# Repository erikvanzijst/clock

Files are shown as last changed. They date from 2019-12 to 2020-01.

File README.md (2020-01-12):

# 24H Digital Clock

This project contains the schematics and PCB layout for a 24-hour digital
quartz clock with self-dimming LED display.

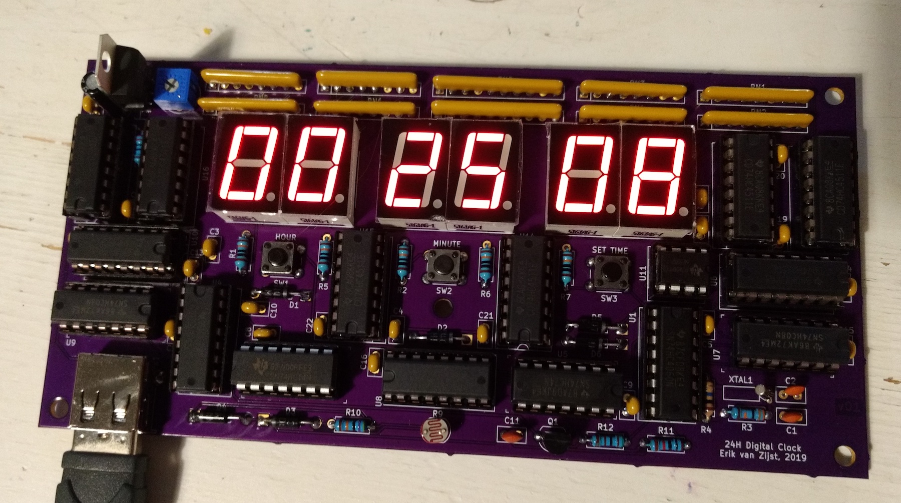
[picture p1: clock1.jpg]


Full write-up is at https://medium.com/@erikvanzijst/a-digital-quartz-clock-from-scratch-a80ec5e427

## Kicad symbol and footprint libraries
The project uses the [DigiKey Kicad symbol and footprint libraries](https://github.com/Digi-Key/digikey-kicad-library).
After cloning or downloading those locally, [add them to the Kicad Symbol and
Footprint libraries](https://forum.digikey.com/t/importing-the-digi-key-kicad-library-into-kicad-5-0-0/4075).

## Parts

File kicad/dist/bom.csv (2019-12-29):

Reference | Quantity | Value | MPN | Digikey Part Number | Price | Total Price | Part Page | Footprint | Category | DK_Datasheet_Link | DK_Detail_Page | Description | Digi-Key_PN | Family | MPN | Manufacturer | Status
C11 | 1 | 47nF |  |  |  |  |  | Capacitor_THT:C_Disc_D5.0mm_W2.5mm_P2.50mm
C12 | 1 | 10nF |  |  |  |  |  | Capacitor_THT:C_Disc_D5.0mm_W2.5mm_P2.50mm
C2 C1 | 2 | 22pF |  |  |  |  |  | Capacitor_THT:C_Disc_D5.0mm_W2.5mm_P2.50mm
C4 C3 C5 C14 C15 C21 C16 C22 C8 C10 C18 C23 C13 C17 C9 C19 C20 C24 | 18 | 100nF | C320C104J5R5TA | 399-9775-ND | $0.48 |  | https://www.digikey.com/product-detail/en/kemet/C320C104J5R5TA/399-9775-ND/3726074 | Capacitor_THT:C_Disc_D5.0mm_W2.5mm_P2.50mm
C6 | 1 | 10uF |  |  |  |  |  | Capacitor_THT:C_Disc_D5.0mm_W2.5mm_P2.50mm
C7 | 1 | 10uF |  |  |  |  |  | Capacitor_THT:C_Radial_D5.0mm_H11.0mm_P2.00mm
D1 D2 D3 D4 | 4 | D |  |  |  |  |  | digikey-footprints:Diode_DO-35_P10mm
J1 | 1 | USB-SS-52100-001 | SS-52100-001 | 380-1412-ND | $0.44 |  | https://www.digikey.com/products/en?keywords=380-1412-ND | KiCad:USB_A_Stewart_SS-52100-001_Horizontal | Connectors, Interconnects |  | https://www.digikey.com/product-detail/en/stewart-connector/SS-52100-001/380-1412-ND/7902377 | CONN RCPT USB2.0 TYPEA 4POS R/A | 380-1412-ND | USB, DVI, HDMI Connectors | SS-52100-001 | Stewart Connector | Active
Q1 | 1 | PN2222A |  |  |  |  |  | Package_TO_SOT_THT:TO-92_Inline_Wide
R10 | 1 | 10K |  |  |  |  |  | Resistor_THT:R_Axial_DIN0207_L6.3mm_D2.5mm_P7.62mm_Horizontal
R11 | 1 | 5.1K |  |  |  |  |  | Resistor_THT:R_Axial_DIN0207_L6.3mm_D2.5mm_P7.62mm_Horizontal
R3 | 1 | 330k | SFR2500003303JA500 | BC4849CT-ND | $0.13 |  | https://www.digikey.com/product-detail/en/vishay-bc-components/SFR2500003303JA500/BC4849CT-ND/7352279 | Resistor_THT:R_Axial_DIN0207_L6.3mm_D2.5mm_P7.62mm_Horizontal
R4 | 1 | 10M | CF14JT10M0 | CF14JT10M0CT-ND | $0.10 |  | https://www.digikey.com/product-detail/en/stackpole-electronics-inc/CF14JT10M0/CF14JT10M0CT-ND/1830444 | Resistor_THT:R_Axial_DIN0207_L6.3mm_D2.5mm_P7.62mm_Horizontal
R6 R2 R5 R1 | 4 | 100K | SFR2500001003FR500 | PPC100KYCT-ND | $0.13 |  | https://www.digikey.com/products/en/resistors/through-hole-resistors/53?k=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 | Resistor_THT:R_Axial_DIN0207_L6.3mm_D2.5mm_P7.62mm_Horizontal
R7 | 1 | 220R | SFR2500002200FR500 | PPC220YCT-ND | $0.13 |  | https://www.digikey.com/product-detail/en/vishay-bc-components/SFR2500002200FR500/PPC220YCT-ND/596957 | Resistor_THT:R_Axial_DIN0207_L6.3mm_D2.5mm_P7.62mm_Horizontal
R8 | 1 | VT93xx | PDV-P7002 | PDV-P7002-ND | $1.41 |  | https://www.digikey.com/product-detail/en/advanced-photonix/PDV-P7002/PDV-P7002-ND/481921 | OptoDevice:R_LDR_4.9x4.2mm_P2.54mm_Vertical
R9 | 1 | 1M |  |  |  |  |  | Resistor_THT:R_Axial_DIN0207_L6.3mm_D2.5mm_P7.62mm_Horizontal
RN1 RN2 RN3 RN4 RN5 RN6 RN7 RN8 | 8 | 150R | 4608X-102-151LF | 4608X-2-151LF-ND | $0.57 |  | https://www.digikey.com/product-detail/en/4608X-102-151LF/4608X-2-151LF-ND/1089113/?itemSeq=299231447 | Resistor_THT:R_Array_SIP8
RN9 RN10 | 2 | 150R | 4610X-102-151LF | 4610X-2-151LF-ND | $0.58 |  | https://www.digikey.com/product-detail/en/4610X-102-151LF/4610X-2-151LF-ND/1089226/?itemSeq=299231416 | Resistor_THT:R_Array_SIP10
RV1 | 1 | 500R | 3362P-1-501LF | 3362P-501LF-ND | $1.02 |  | https://www.digikey.com/product-detail/en/3362P-1-501LF/3362P-501LF-ND/1088420/?itemSeq=298643928 | Potentiometer_THT:Potentiometer_Bourns_3339P_Vertical_HandSoldering
SW1 | 1 | HOUR |  |  |  |  |  | Button_Switch_THT:SW_PUSH_6mm_H4.3mm
SW2 | 1 | MIN |  |  |  |  |  | Button_Switch_THT:SW_PUSH_6mm_H4.3mm
SW3 | 1 | TIME |  |  |  |  |  | Button_Switch_THT:SW_PUSH_6mm_H4.3mm
U1 | 1 | 74HC4060 | SN74HC4060N | 296-8209-5-ND | $0.58 |  | https://www.digikey.com/product-detail/en/texas-instruments/SN74HC4060N/296-8209-5-ND/386620 | Package_DIP:DIP-16_W7.62mm_Socket
U11 | 1 | NE555P | NE555P | 296-1411-5-ND | $0.45 |  | https://www.digikey.com/product-detail/en/NE555P/296-1411-5-ND/277057/?itemSeq=291832413 | Package_DIP:DIP-8_W7.62mm_Socket | Integrated Circuits (ICs) | http://www.ti.com/general/docs/suppproductinfo.tsp?distId=10 | /product-detail/en/texas-instruments/NE555P/296-1411-5-ND/277057 | IC OSC SINGLE TIMER 100KHZ 8-DIP | 296-1411-5-ND | Clock/Timing - Programmable Timers and Oscillators | NE555P | Texas Instruments | Active
U12 U14 U15 U16 U13 U17 | 6 | 74HC4511 | CD74HC4511E | 296-14537-5-ND | $0.85 |  | https://www.digikey.com/product-detail/en/texas-instruments/CD74HC4511E/296-14537-5-ND/555825 | Package_DIP:DIP-16_W7.62mm_Socket
U18 U19 U20 U21 U23 U22 | 6 | KCSC02-105 |  |  |  |  | https://www.velleman.eu/downloads/29/infosheets/vmp502_sma42056etc.pdf | Display_7Segment:7SegmentLED_LTS6760_LTS6780
U2 | 1 | LD1117V | LD1117V | 497-7310-5-ND | $0.55 |  | https://www.digikey.com/product-detail/en/LD1117V/497-7310-5-ND/1038361/?itemSeq=298871373 | digikey-footprints:TO-220-3 | Integrated Circuits (ICs) | http://www.st.com/content/ccc/resource/technical/document/datasheet/99/3b/7d/91/91/51/4b/be/CD00000544.pdf/files/CD00000544.pdf/jcr:content/translations/en.CD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 | /product-detail/en/stmicroelectronics/LD1117V33/497-1491-5-ND/586012 | IC REG LINEAR 1.8V-5V 800MA TO220AB | 497-7310-5-ND | PMIC - Voltage Regulators - Linear | LD1117V | STMicroelectronics | Active
U3 | 1 | 74HC14 | SN74HC14N | 296-1577-5-ND | $0.55 |  | https://www.digikey.com/product-detail/en/texas-instruments/SN74HC14N/296-1577-5-ND/277223 | clock:Socket_DIP-14_0.775in_Conn
U4 | 1 | 74HC157 | SN74HC157N | 296-1578-5-ND | $0.50 |  | https://www.digikey.com/product-detail/en/SN74HC157N/296-1578-5-ND/277224/?itemSeq=291832408 | Package_DIP:DIP-16_W7.62mm_Socket
U5 | 1 | SN74HC74N | SN74HC74N | 296-1602-5-ND | $0.48 |  | https://www.digikey.com/product-detail/en/texas-instruments/SN74HC74N/296-1602-5-ND/277248 | clock:Socket_DIP-14_0.775in_Conn | Integrated Circuits (ICs) | http://www.ti.com/general/docs/suppproductinfo.tsp?distId=10 | /product-detail/en/texas-instruments/SN74HC74N/296-1602-5-ND/277248 | IC FF D-TYPE DUAL 1BIT 14DIP | 296-1602-5-ND | Logic - Flip Flops | SN74HC74N | Texas Instruments | Active
U6 U8 U10 | 3 | 74HC390 | CD74HC390E | 296-9199-5-ND | $0.70 |  | https://www.digikey.com/product-detail/en/texas-instruments/CD74HC390E/296-9199-5-ND/376757 | Package_DIP:DIP-16_W7.62mm_Socket
U9 U7 | 2 | 74HC08 |  |  |  |  |  | clock:Socket_DIP-14_0.775in_Conn
XTAL1 | 1 | ECS-_327-12_5-34B-TR | ECS-.327-CDX-1038 | XC2121-ND | $0.60 |  | https://www.digikey.com/product-detail/en/ecs-inc/ECS-.327-CDX-1038/XC2121-ND/5875500 | Crystal:Crystal_DS26_D2.0mm_L6.0mm_Horizontal | Crystals, Oscillators, Resonators | http://www.ecsxtal.com/store/pdf/ecx-31b.pdf | /product-detail/en/ecs-inc/ECS-.327-12.5-34B-TR/XC1617CT-ND/1693786 | CRYSTAL 32.7680KHZ 12.5PF SMD | XC1617CT-ND | Crystals | ECS-.327-12.5-34B-TR | ECS Inc. | Active
DIP Socket 8 Pins | 1 | DIP Socket 8 Pins | ED08DT | ED3044-5-ND | $0.16 |  | https://www.digikey.com/product-detail/en/on-shore-technology-inc/ED08DT/ED3044-5-ND/4147594
DIP Socket 14 Pins | 4 | DIP Socket 14 Pins | A 14-LC-TT | AE9989-ND | $0.22 |  | https://www.digikey.com/product-detail/en/assmann-wsw-components/A-14-LC-TT/AE9989-ND/821743
DIP Socket 16 Pins | 11 | DIP Socket 16 Pins | ED16DT | ED3046-5-ND | $0.19 |  | https://www.digikey.com/product-detail/en/on-shore-technology-inc/ED16DT/ED3046-5-ND/4147596

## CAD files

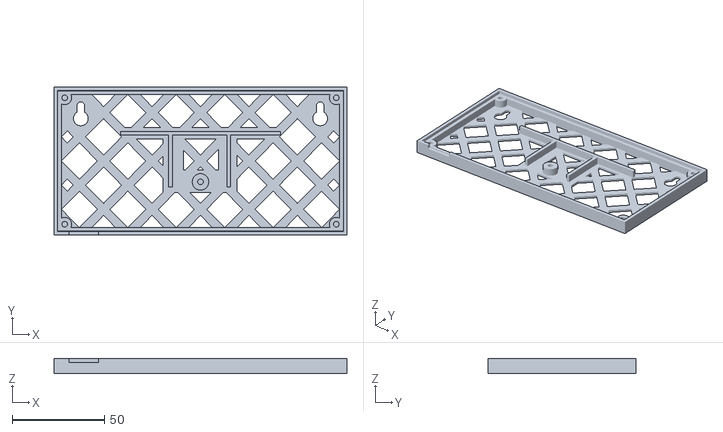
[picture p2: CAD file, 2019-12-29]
base_plate.stl
158.5 x 80.0 x 8.00

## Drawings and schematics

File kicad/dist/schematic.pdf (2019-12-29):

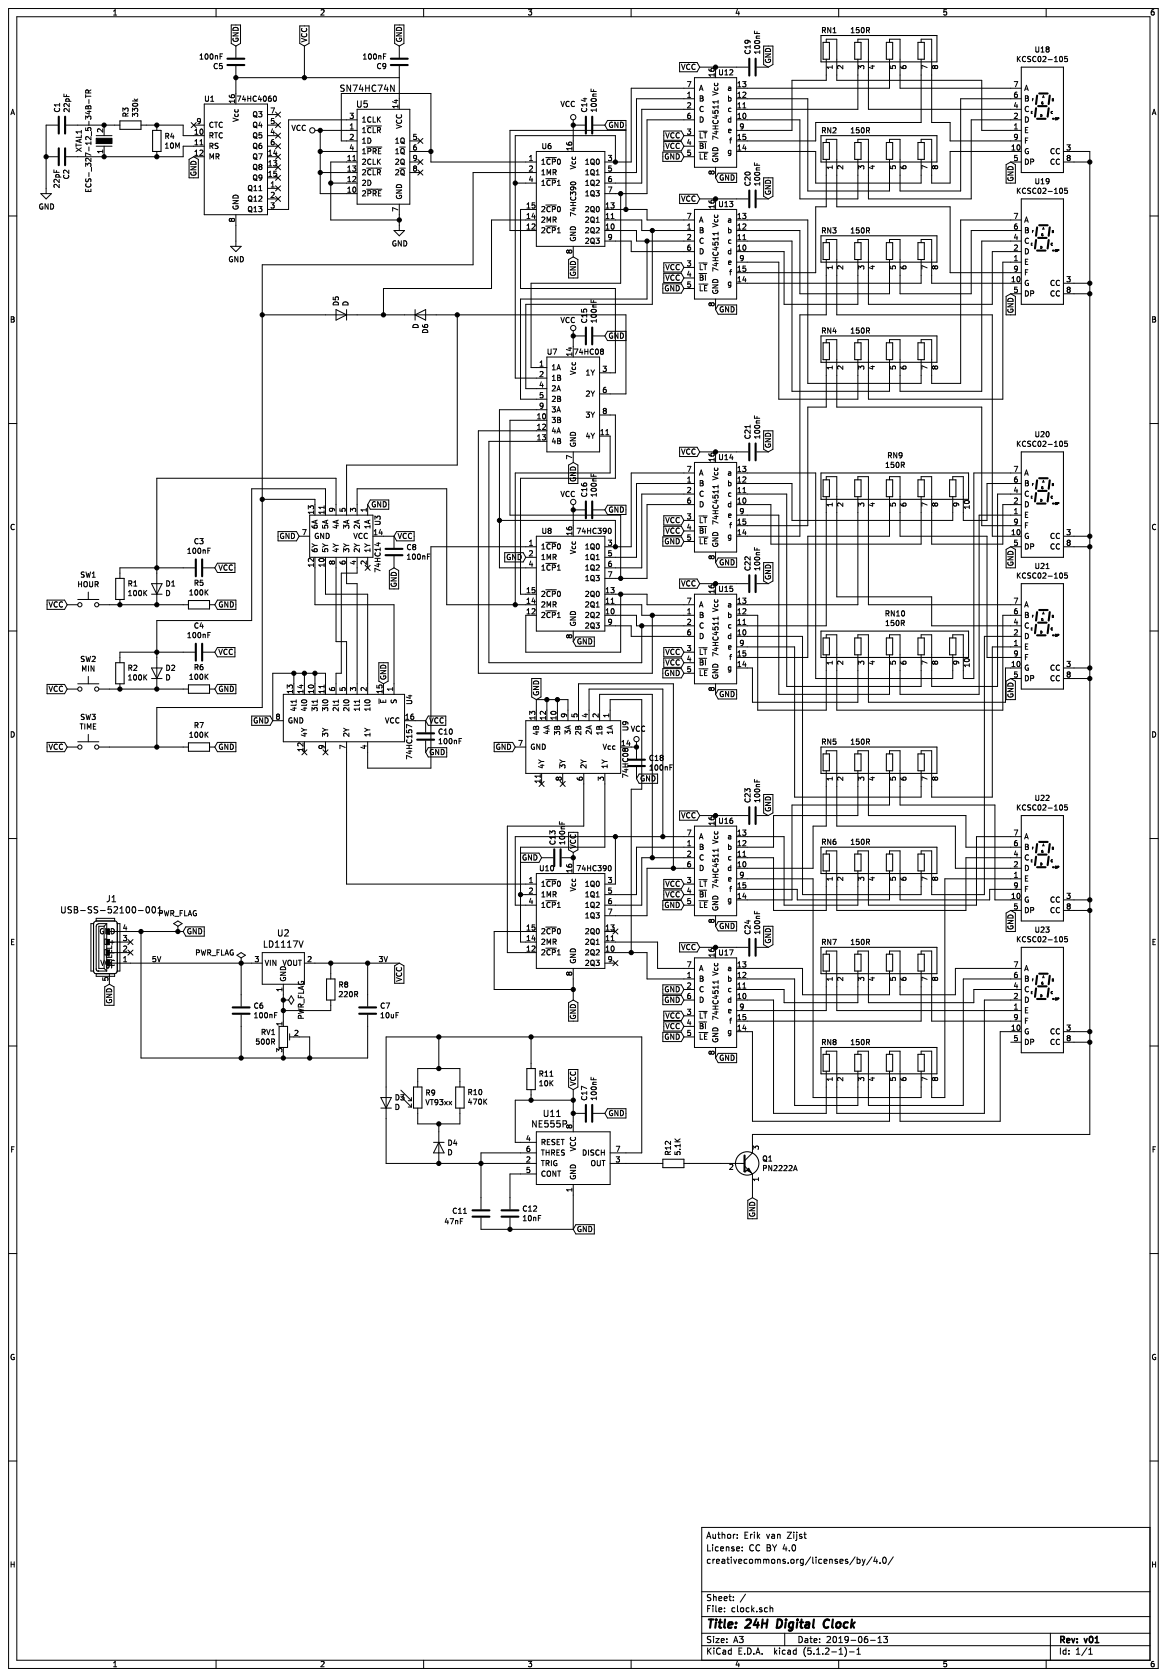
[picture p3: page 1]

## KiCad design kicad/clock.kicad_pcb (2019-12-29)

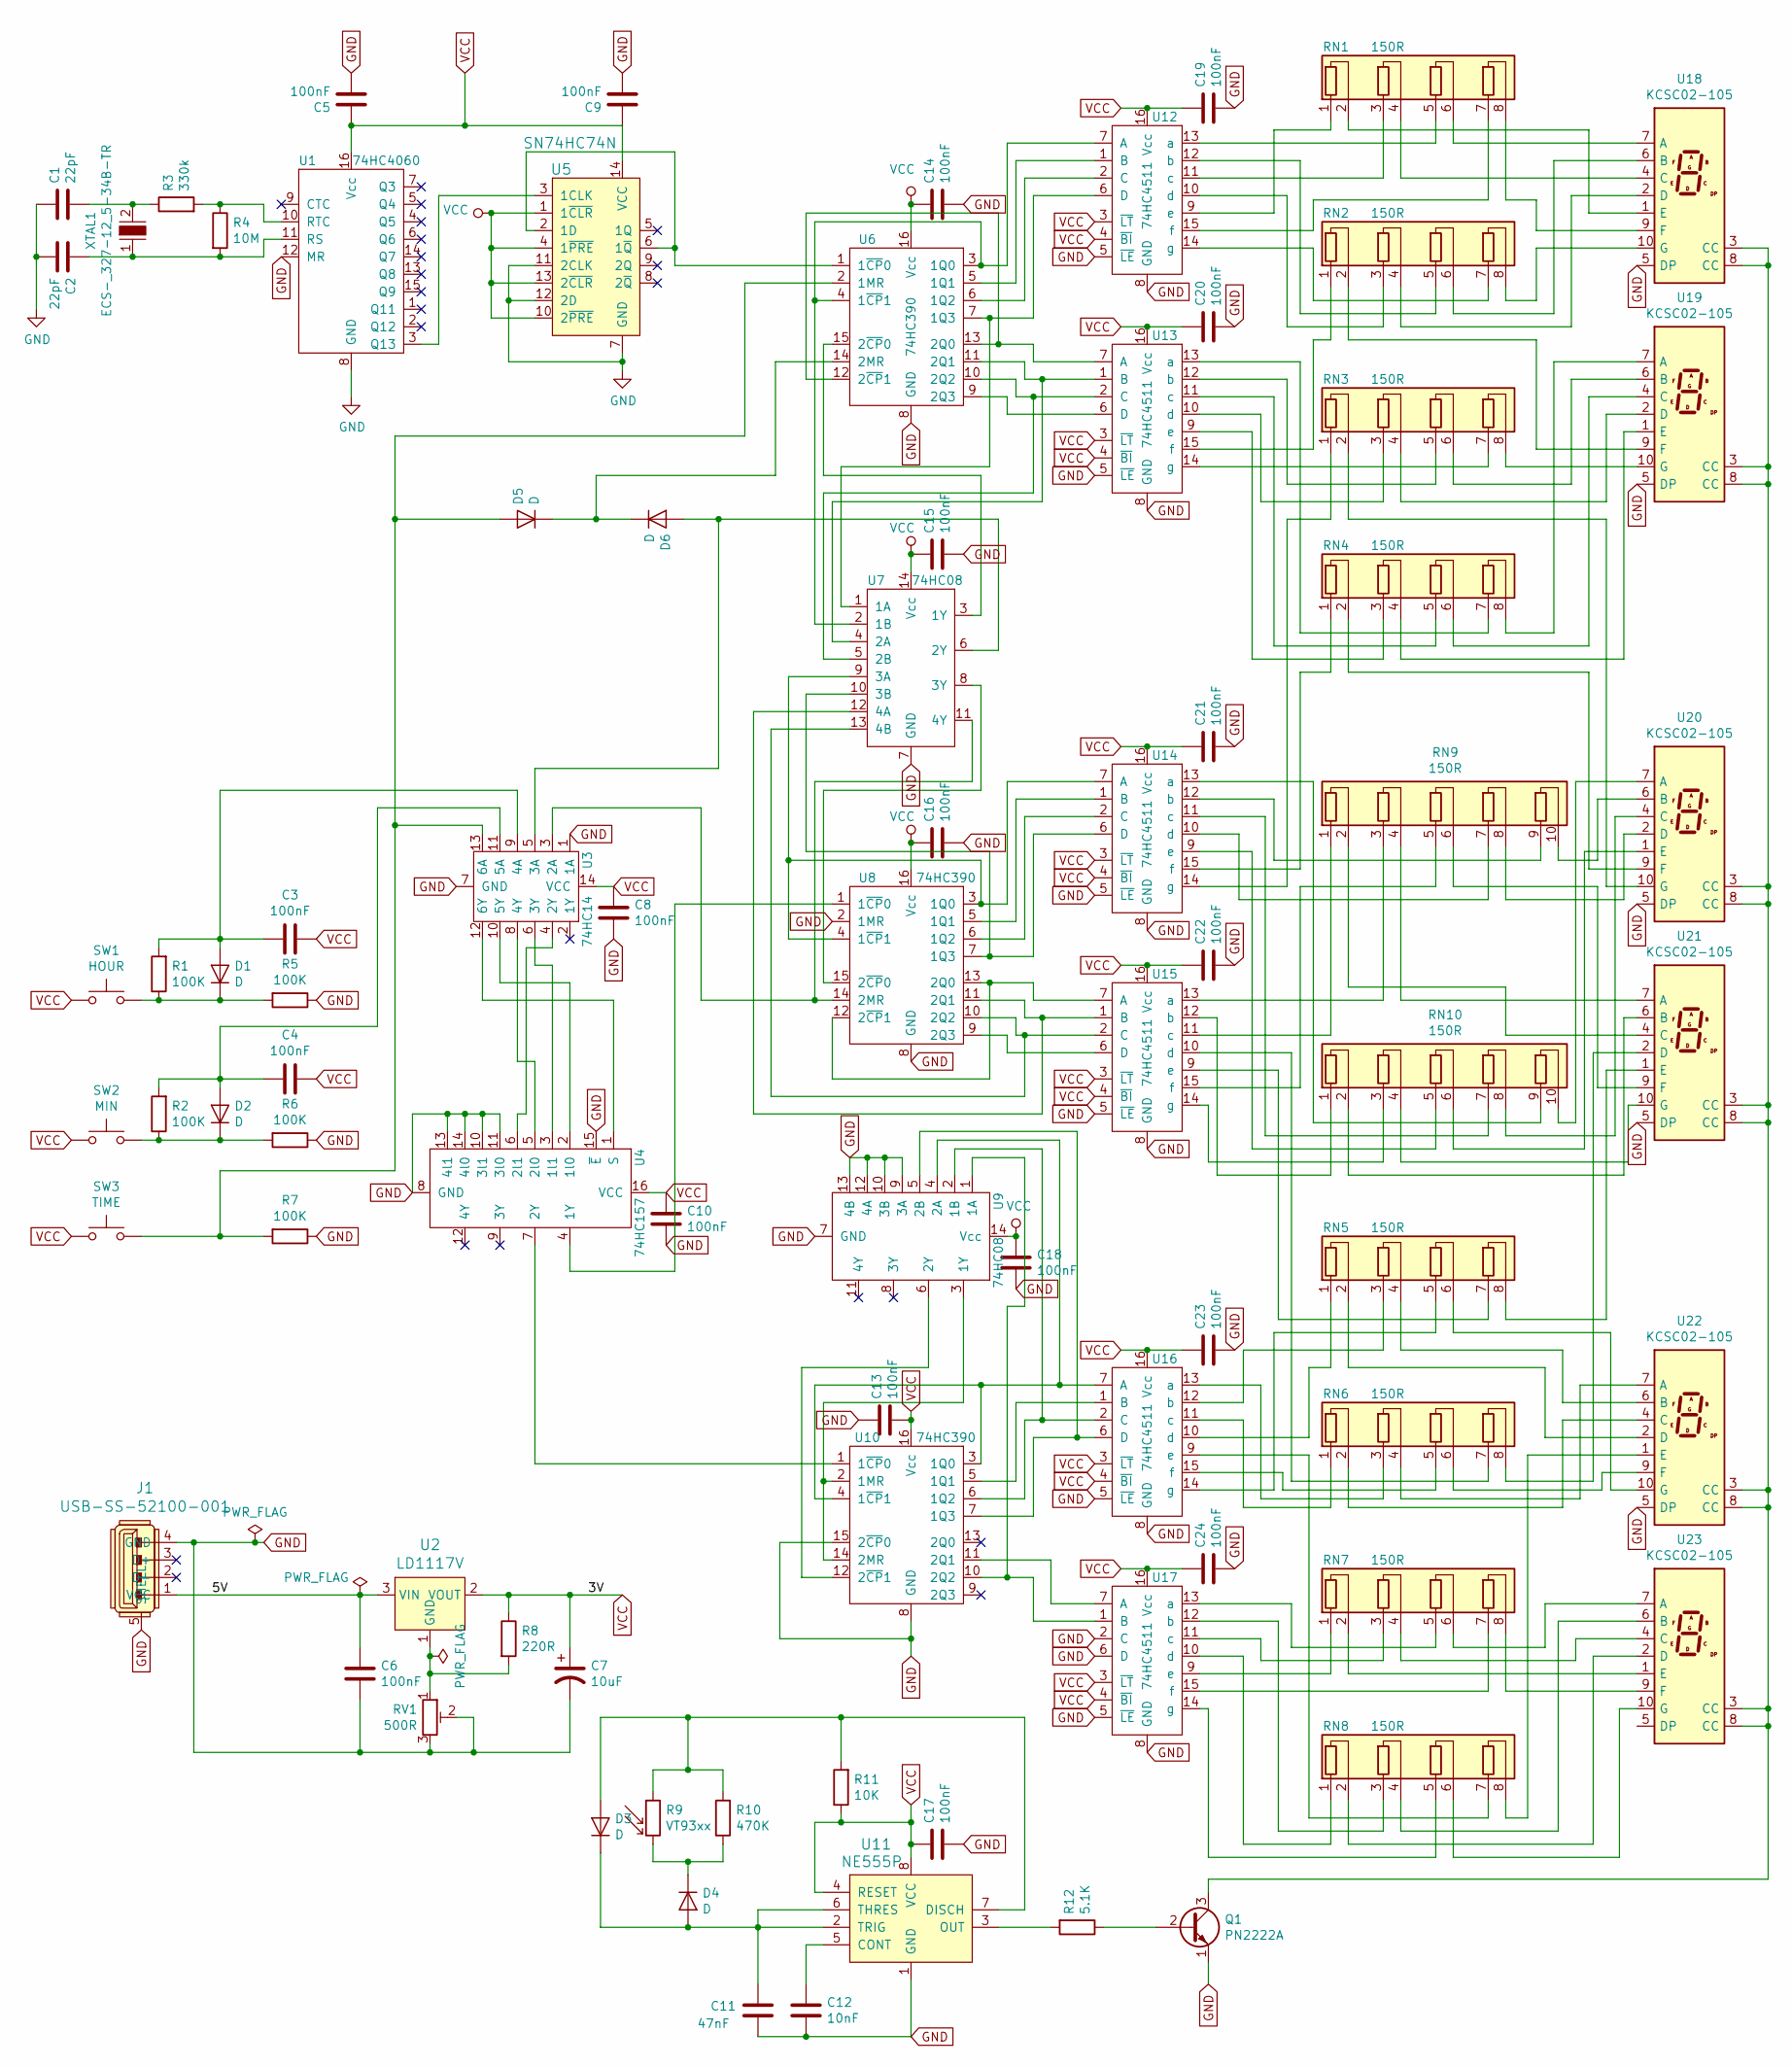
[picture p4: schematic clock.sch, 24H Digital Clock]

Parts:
C1, C2: 22pF; C_Disc_D5.0mm_W2.5mm_P2.50mm
C3, C4, C5, C6, C8, C9, C10, C13, C14, C15, C16, C17, C18, C19, C20, C21, C22, C23, C24: 100nF; C_Disc_D5.0mm_W2.5mm_P2.50mm
C7: 10uF; CP_Radial_Tantal_D5.0mm_P2.50mm
C11: 47nF; C_Disc_D5.0mm_W2.5mm_P2.50mm
C12: 10nF; C_Disc_D5.0mm_W2.5mm_P2.50mm
D1, D2, D3, D4, D5, D6: D; Diode_DO-35_P10mm
J1: USB-SS-52100-001; USB_A_Stewart_SS-52100-001_Horizontal; MPN SS-52100-001; Digi-Key_PN 380-1412-ND
Q1: PN2222A; TO-92_Inline_Wide
R1, R2, R5, R6, R7: 100K; R_Axial_DIN0207_L6.3mm_D2.5mm_P7.62mm_Horizontal
R3: 330k; R_Axial_DIN0207_L6.3mm_D2.5mm_P7.62mm_Horizontal
R4: 10M; R_Axial_DIN0207_L6.3mm_D2.5mm_P7.62mm_Horizontal
R8: 220R; R_Axial_DIN0207_L6.3mm_D2.5mm_P7.62mm_Horizontal
R9: VT93xx; R_LDR_4.9x4.2mm_P2.54mm_Vertical
R10: 470K; R_Axial_DIN0207_L6.3mm_D2.5mm_P7.62mm_Horizontal
R11: 10K; R_Axial_DIN0207_L6.3mm_D2.5mm_P7.62mm_Horizontal
R12: 5.1K; R_Axial_DIN0207_L6.3mm_D2.5mm_P7.62mm_Horizontal
RN1, RN2, RN3, RN4, RN5, RN6, RN7, RN8: 150R; R_Array_SIP8
RN9, RN10: 150R; R_Array_SIP10
RV1: 500R; Potentiometer_Bourns_3339P_Vertical_HandSoldering
SW1: HOUR; SW_PUSH_6mm_H4.3mm
SW2: MIN; SW_PUSH_6mm_H4.3mm
SW3: TIME; SW_PUSH_6mm_H4.3mm
U1: 74HC4060; DIP-16_W7.62mm_Socket
U2: LD1117V; TO-220-3; MPN LD1117V; Digi-Key_PN 497-7310-5-ND
U3: 74HC14; Socket_DIP-14_0.775in_Conn
U4: 74HC157; DIP-16_W7.62mm_Socket
U5: SN74HC74N; Socket_DIP-14_0.775in_Conn; MPN SN74HC74N; Digi-Key_PN 296-1602-5-ND
U6, U8, U10: 74HC390; DIP-16_W7.62mm_Socket
U7, U9: 74HC08; Socket_DIP-14_0.775in_Conn
U11: NE555P; DIP-8_W7.62mm_Socket; MPN NE555P; Digi-Key_PN 296-1411-5-ND
U12, U13, U14, U15, U16, U17: 74HC4511; DIP-16_W7.62mm_Socket
U18, U19, U20, U21, U22, U23: KCSC02-105; 7SegmentLED_LTS6760_LTS6780
XTAL1: ECS-_327-12_5-34B-TR; Crystal_DS26_D2.0mm_L6.0mm_Horizontal; MPN ECS-.327-12.5-34B-TR; Digi-Key_PN XC1617CT-ND

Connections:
/5V: C6.1, J1.1 (VCC), U2.3 (VIN)
GND: C1.1, C2.2, C5.2, C6.2, C7.2, C8.2, C9.2, C10.2, C11.2, C12.2, C13.1, C14.2, C15.2, C16.2, C17.2, C18.2, C19.2, C20.2, C21.2, C22.2, C23.2, C24.2, J1.4 (GND), J1.5 (SHELL), Q1.1 (E), R5.1, R6.1, R7.1, RV1.2, RV1.3, U1.8 (GND), U1.12 (MR), U3.1 (1A), U3.7 (GND), U4.8 (GND), U4.10 (3l1), U4.11 (3l0), U4.13 (4l1), U4.14 (4l0), U4.15 (~E), U5.7 (GND), U5.11 (2CLK), U5.12 (2D), U6.8 (GND), U7.7 (GND), U8.2 (1MR), U8.8 (GND), U9.7 (GND), U9.9 (3A), U9.10 (3B), U9.12 (4A), U9.13 (4B), U10.8 (GND), U10.15 (2~CP~0), U11.1 (GND), U12.5 (~LE), U12.8 (GND), U13.5 (~LE), U13.8 (GND), U14.5 (~LE), U14.8 (GND), U15.5 (~LE), U15.8 (GND), U16.5 (~LE), U16.8 (GND), U17.2 (C), U17.5 (~LE), U17.6 (D), U17.8 (GND), U18.5 (DP), U19.5 (DP), U20.5 (DP), U21.5 (DP), U22.5 (DP)
unnamed: C1.2, R3.1, XTAL1.2
unnamed: C2.1, R4.2, U1.11 (RS), XTAL1.1
unnamed: C3.2, D1.2 (A), R1.2, U3.9 (4A)
unnamed: C4.2, D2.2 (A), R2.2, U3.11 (5A)
unnamed: C11.1, D3.1 (K), D4.2 (A), U11.2 (TRIG), U11.6 (THRES)
unnamed: C12.1, U11.5 (CONT)
unnamed: D1.1 (K), R1.1, R5.2, SW1.2
unnamed: D2.1 (K), R2.1, R6.2, SW2.2
unnamed: D3.2 (A), R9.1, R10.2, R11.2, U11.7 (DISCH)
unnamed: D4.1 (K), R9.2, R10.1
unnamed: D5.1 (K), D6.1 (K), U6.14 (2MR)
unnamed: D5.2 (A), R7.2, SW3.2, U3.13 (6A), U6.2 (1MR)
unnamed: D6.2 (A), U3.5 (3A), U7.6 (2Y)
unnamed: Q1.2 (B), R12.1
unnamed: Q1.3 (C), U18.3 (CC), U18.8 (CC), U19.3 (CC), U19.8 (CC), U20.3 (CC), U20.8 (CC), U21.3 (CC), U21.8 (CC), U22.3 (CC), U22.8 (CC), U23.3 (CC), U23.8 (CC)
unnamed: R3.2, R4.1, U1.10 (RTC)
unnamed: R8.2, RV1.1, U2.1 (GND)
unnamed: R12.2, U11.3 (OUT)
unnamed: RN1.1 (R1.1), U12.9 (e)
unnamed: RN1.2 (R1.2), U18.1 (E)
unnamed: RN1.3 (R2.1), U12.11 (c)
unnamed: RN1.4 (R2.2), U18.4 (C)
unnamed: RN1.5 (R3.1), U12.13 (a)
unnamed: RN1.6 (R3.2), U18.7 (A)
unnamed: RN1.7 (R4.1), U12.15 (f)
unnamed: RN1.8 (R4.2), U18.9 (F)
unnamed: RN2.1 (R1.1), U13.15 (f)
unnamed: RN2.2 (R1.2), U19.9 (F)
unnamed: RN2.3 (R2.1), U12.10 (d)
unnamed: RN2.4 (R2.2), U18.2 (D)
unnamed: RN2.5 (R3.1), U12.12 (b)
unnamed: RN2.6 (R3.2), U18.6 (B)
unnamed: RN2.7 (R4.1), U12.14 (g)
unnamed: RN2.8 (R4.2), U18.10 (G)
unnamed: RN3.1 (R1.1), U14.14 (g)
unnamed: RN3.2 (R1.2), U20.10 (G)
unnamed: RN3.3 (R2.1), U13.10 (d)
unnamed: RN3.4 (R2.2), U19.2 (D)
unnamed: RN3.5 (R3.1), U13.12 (b)
unnamed: RN3.6 (R3.2), U19.6 (B)
unnamed: RN3.7 (R4.1), U13.14 (g)
unnamed: RN3.8 (R4.2), U19.10 (G)
unnamed: RN4.1 (R1.1), U14.15 (f)
unnamed: RN4.2 (R1.2), U20.9 (F)
unnamed: RN4.3 (R2.1), U13.9 (e)
unnamed: RN4.4 (R2.2), U19.1 (E)
unnamed: RN4.5 (R3.1), U13.11 (c)
unnamed: RN4.6 (R3.2), U19.4 (C)
unnamed: RN4.7 (R4.1), U13.13 (a)
unnamed: RN4.8 (R4.2), U19.7 (A)
unnamed: RN5.1 (R1.1), U16.10 (d)
unnamed: RN5.2 (R1.2), U22.2 (D)
unnamed: RN5.3 (R2.1), U16.12 (b)
unnamed: RN5.4 (R2.2), U22.6 (B)
unnamed: RN5.5 (R3.1), U16.14 (g)
unnamed: RN5.6 (R3.2), U22.10 (G)
unnamed: RN5.7 (R4.1), U15.9 (e)
unnamed: RN5.8 (R4.2), U21.1 (E)
unnamed: RN6.1 (R1.1), U16.11 (c)
unnamed: RN6.2 (R1.2), U22.4 (C)
unnamed: RN6.3 (R2.1), U16.13 (a)
unnamed: RN6.4 (R2.2), U22.7 (A)
unnamed: RN6.5 (R3.1), U16.15 (f)
unnamed: RN6.6 (R3.2), U22.9 (F)
unnamed: RN6.7 (R4.1), U15.10 (d)
unnamed: RN6.8 (R4.2), U21.2 (D)
unnamed: RN7.1 (R1.1), U17.9 (e)
unnamed: RN7.2 (R1.2), U23.1 (E)
unnamed: RN7.3 (R2.1), U17.11 (c)
unnamed: RN7.4 (R2.2), U23.4 (C)
unnamed: RN7.5 (R3.1), U17.13 (a)
unnamed: RN7.6 (R3.2), U23.7 (A)
unnamed: RN7.7 (R4.1), U17.15 (f)
unnamed: RN7.8 (R4.2), U23.9 (F)
unnamed: RN8.1 (R1.1), U17.10 (d)
unnamed: RN8.2 (R1.2), U23.2 (D)
unnamed: RN8.3 (R2.1), U17.12 (b)
unnamed: RN8.4 (R2.2), U23.6 (B)
unnamed: RN8.5 (R3.1), U17.14 (g)
unnamed: RN8.6 (R3.2), U23.10 (G)
unnamed: RN8.7 (R4.1), U16.9 (e)
unnamed: RN8.8 (R4.2), U22.1 (E)
unnamed: RN9.1 (R1.1), U15.11 (c)
unnamed: RN9.2 (R1.2), U21.4 (C)
unnamed: RN9.3 (R2.1), U15.13 (a)
unnamed: RN9.4 (R2.2), U21.7 (A)
unnamed: RN9.5 (R3.1), U15.15 (f)
unnamed: RN9.6 (R3.2), U21.9 (F)
unnamed: RN9.7 (R4.1), U14.10 (d)
unnamed: RN9.8 (R4.2), U20.2 (D)
unnamed: RN9.9 (R5.1), U14.12 (b)
unnamed: RN9.10 (R5.2), U20.6 (B)
unnamed: RN10.1 (R1.1), U15.12 (b)
unnamed: RN10.2 (R1.2), U21.6 (B)
unnamed: RN10.3 (R2.1), U15.14 (g)
unnamed: RN10.4 (R2.2), U21.10 (G)
unnamed: RN10.5 (R3.1), U14.9 (e)
unnamed: RN10.6 (R3.2), U20.1 (E)
unnamed: RN10.7 (R4.1), U14.11 (c)
unnamed: RN10.8 (R4.2), U20.4 (C)
unnamed: RN10.9 (R5.1), U14.13 (a)
unnamed: RN10.10 (R5.2), U20.7 (A)
unnamed: U1.3 (Q13), U5.3 (1CLK)
unnamed: U3.3 (2A), U7.11 (4Y), U8.14 (2MR)
unnamed: U3.4 (2Y), U4.6 (2l1)
unnamed: U3.6 (3Y), U4.3 (1l1)
unnamed: U3.8 (4Y), U4.5 (2l0)
unnamed: U3.10 (5Y), U4.2 (1l0)
unnamed: U3.12 (6Y), U4.1 (S)
unnamed: U4.4 (1Y), U8.1 (1~CP~0)
unnamed: U5.2 (1D), U5.6 (1~Q), U6.1 (1~CP~0)
unnamed: U6.15 (2~CP~0), U7.3 (1Y)
unnamed: U7.8 (3Y), U8.15 (2~CP~0)
unnamed: U4.7 (2Y), U10.1 (1~CP~0)
unnamed: U9.4 (2A), U10.3 (1Q0), U10.4 (1~CP~1), U16.7 (A)
unnamed: U10.5 (1Q1), U16.1 (B)
unnamed: U9.2 (1B), U10.6 (1Q2), U16.2 (C)
unnamed: U9.5 (2B), U10.7 (1Q3), U16.6 (D)
unnamed: U9.1 (1A), U10.10 (2Q2), U17.1 (B)
unnamed: U10.11 (2Q1), U17.7 (A)
unnamed: U9.6 (2Y), U10.12 (2~CP~1)
unnamed: U9.3 (1Y), U10.2 (1MR), U10.14 (2MR)
unnamed: U6.5 (1Q1), U12.1 (B)
unnamed: U6.6 (1Q2), U12.2 (C)
unnamed: U6.7 (1Q3), U7.1 (1A), U12.6 (D)
unnamed: U6.3 (1Q0), U6.4 (1~CP~1), U7.2 (1B), U12.7 (A)
unnamed: U6.11 (2Q1), U7.4 (2A), U13.1 (B)
unnamed: U6.10 (2Q2), U7.5 (2B), U13.2 (C)
unnamed: U6.9 (2Q3), U13.6 (D)
unnamed: U6.12 (2~CP~1), U6.13 (2Q0), U13.7 (A)
unnamed: U8.5 (1Q1), U14.1 (B)
unnamed: U8.6 (1Q2), U14.2 (C)
unnamed: U7.10 (3B), U8.7 (1Q3), U14.6 (D)
unnamed: U7.9 (3A), U8.3 (1Q0), U8.4 (1~CP~1), U14.7 (A)
unnamed: U7.12 (4A), U8.11 (2Q1), U15.1 (B)
unnamed: U7.13 (4B), U8.10 (2Q2), U15.2 (C)
unnamed: U8.9 (2Q3), U15.6 (D)
unnamed: U8.12 (2~CP~1), U8.13 (2Q0), U15.7 (A)
VCC: C3.1, C4.1, C5.1, C7.1, C8.1, C9.1, C10.1, C13.2, C14.1, C15.1, C16.1, C17.1, C18.1, C19.1, C20.1, C21.1, C22.1, C23.1, C24.1, R8.1, R11.1, SW1.1, SW2.1, SW3.1, U1.16 (Vcc), U2.2 (VOUT), U3.14 (VCC), U4.16 (VCC), U5.1 (1~CLR), U5.4 (1~PRE), U5.10 (2~PRE), U5.13 (2~CLR), U5.14 (VCC), U6.16 (Vcc), U7.14 (Vcc), U8.16 (Vcc), U9.14 (Vcc), U10.16 (Vcc), U11.4 (RESET), U11.8 (VCC), U12.3 (~LT), U12.4 (~BI), U12.16 (Vcc), U13.3 (~LT), U13.4 (~BI), U13.16 (Vcc), U14.3 (~LT), U14.4 (~BI), U14.16 (Vcc), U15.3 (~LT), U15.4 (~BI), U15.16 (Vcc), U16.3 (~LT), U16.4 (~BI), U16.16 (Vcc), U17.3 (~LT), U17.4 (~BI), U17.16 (Vcc)

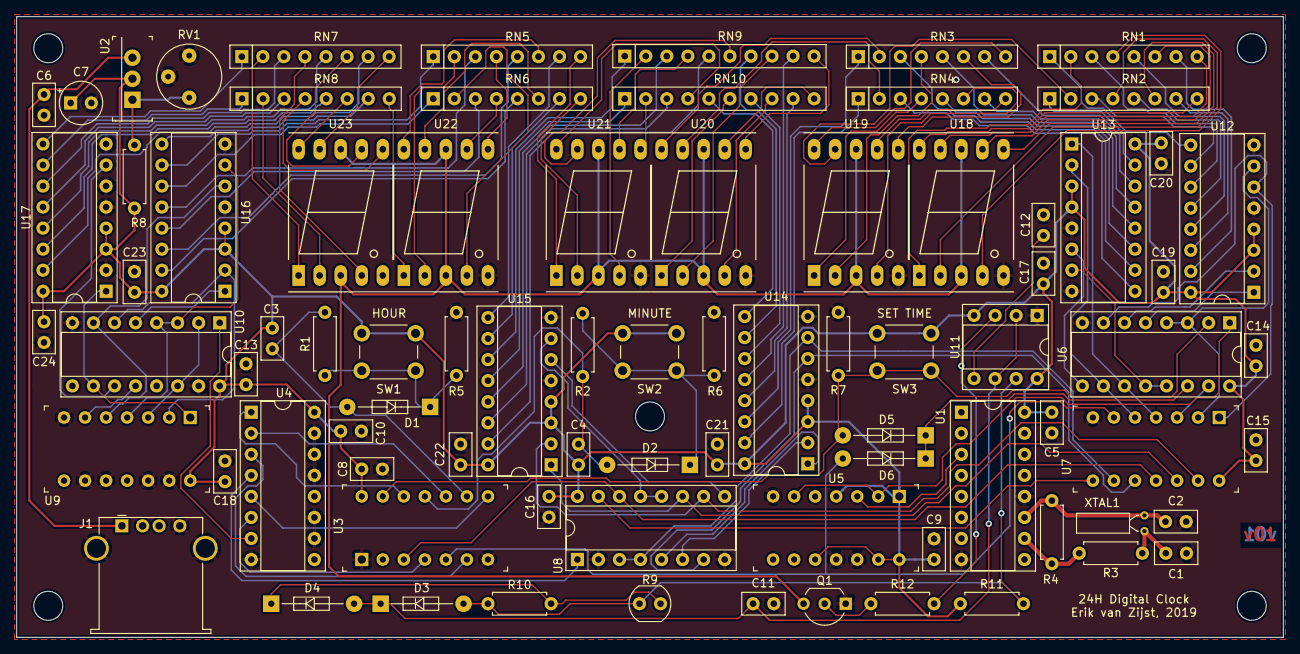
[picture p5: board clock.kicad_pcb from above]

Board: 2 copper layers, 152.9 x 74.9 mm, 82 parts (0 on the bottom side), 141 nets.

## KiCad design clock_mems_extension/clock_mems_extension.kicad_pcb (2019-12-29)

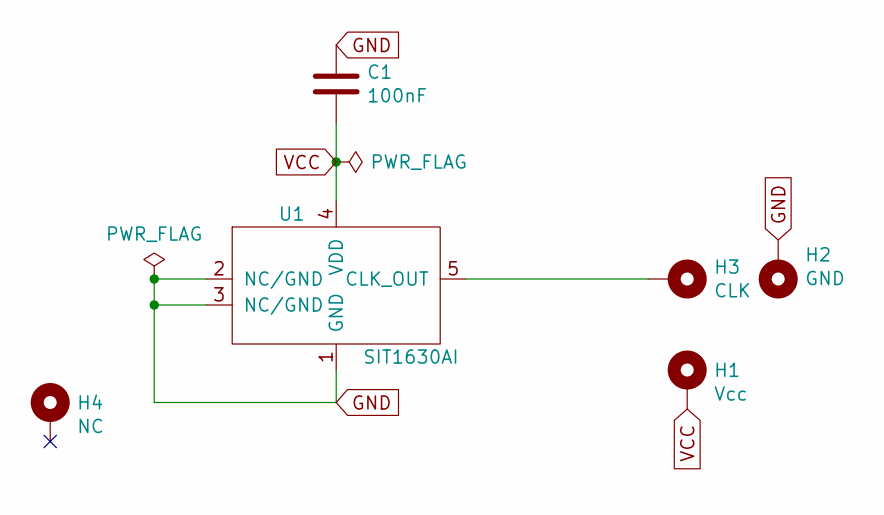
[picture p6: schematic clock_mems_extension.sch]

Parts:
C1: 100nF; C_0603_1608Metric_Pad1.05x0.95mm_HandSolder
H1: Vcc; Pin_D0.8mm
H2: GND; Pin_D0.8mm
H3: CLK; Pin_D0.8mm
H4: NC; Pin_D0.8mm
U1: SIT1630AI; SOT-23-5_HandSoldering

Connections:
GND: C1.1, H2.1, U1.1 (GND), U1.2 (NC/GND), U1.3 (NC/GND)
unnamed: H3.1, U1.5 (CLK_OUT)
VCC: C1.2, H1.1, U1.4 (VDD)

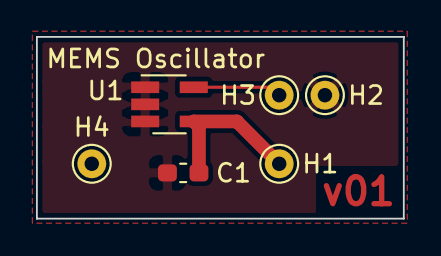
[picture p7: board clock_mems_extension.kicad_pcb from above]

Board: 2 copper layers, 20.4 x 10.1 mm, 6 parts (0 on the bottom side), 3 nets.

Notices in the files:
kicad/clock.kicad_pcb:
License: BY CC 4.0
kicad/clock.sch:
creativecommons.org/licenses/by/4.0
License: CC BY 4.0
